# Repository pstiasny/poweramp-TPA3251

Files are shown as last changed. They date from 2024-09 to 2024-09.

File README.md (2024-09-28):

TPA3251-based power amplifier, 2x150W
=====================================

* [View schematic in KiCanvas](https://kicanvas.org/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)
* [View board in KiCanvas](https://kicanvas.org/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)

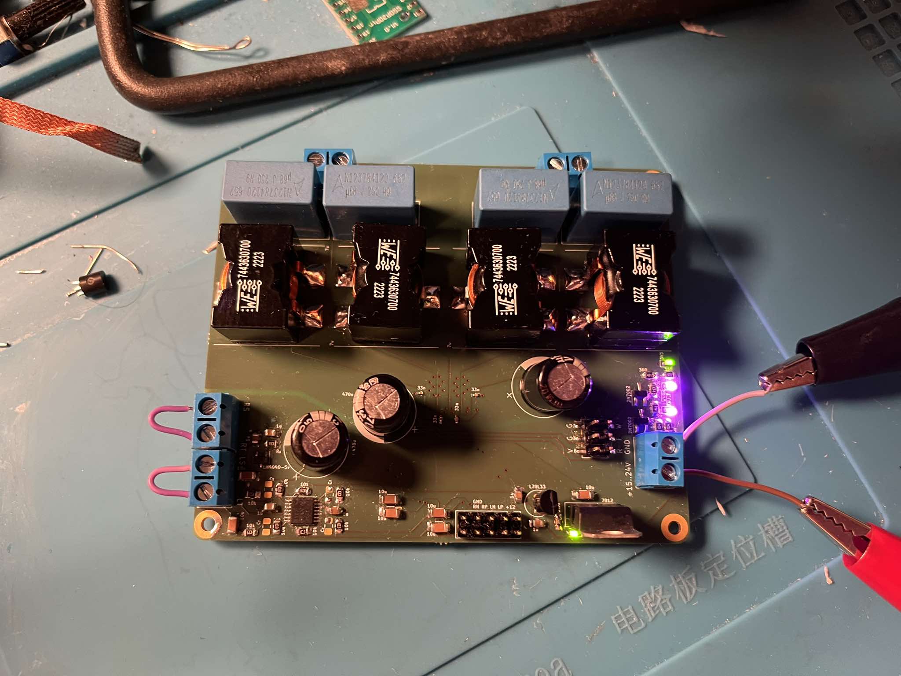
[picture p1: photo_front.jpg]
photo of the top side


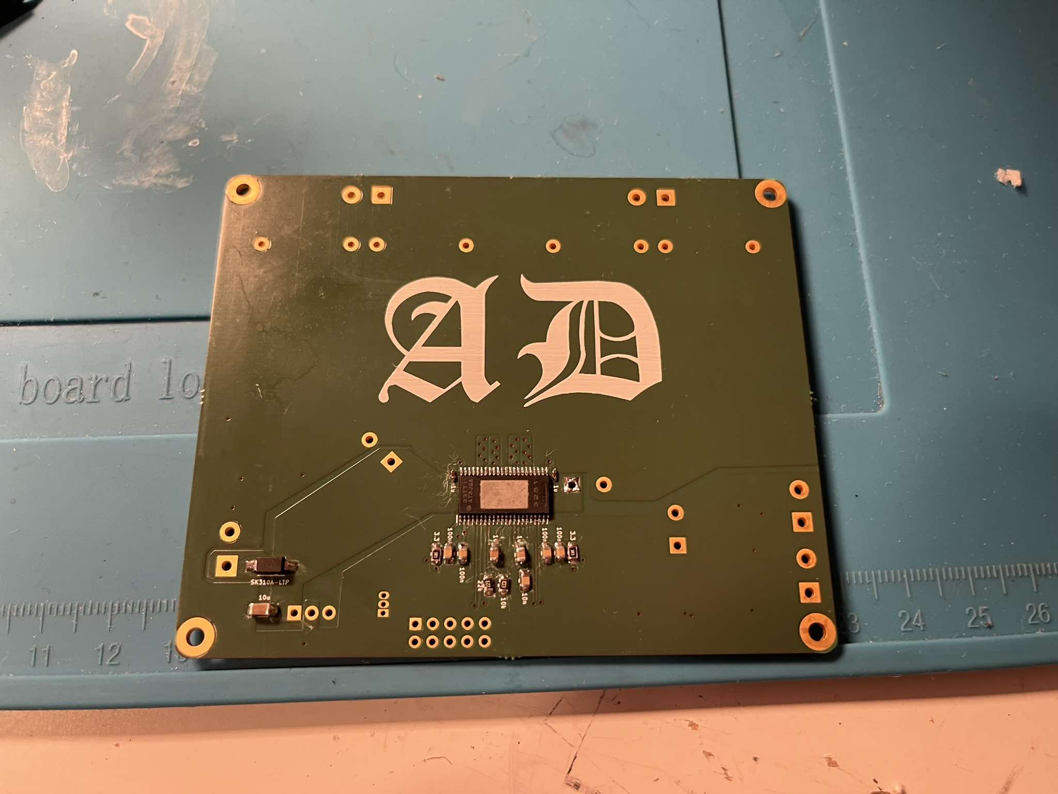
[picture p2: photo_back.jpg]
photo of the back side


## Notes

*  Amplifier chip is placed on the bottom side.  That design allows for thermal coupling to chassis.
*  I had the board bend a little.  Might be better balanced without the bottom layer ground plane.
*  DC relative to power ground will be present on the ouput terminals.  Add AC coupling capacitors
   in series if that is undesired.

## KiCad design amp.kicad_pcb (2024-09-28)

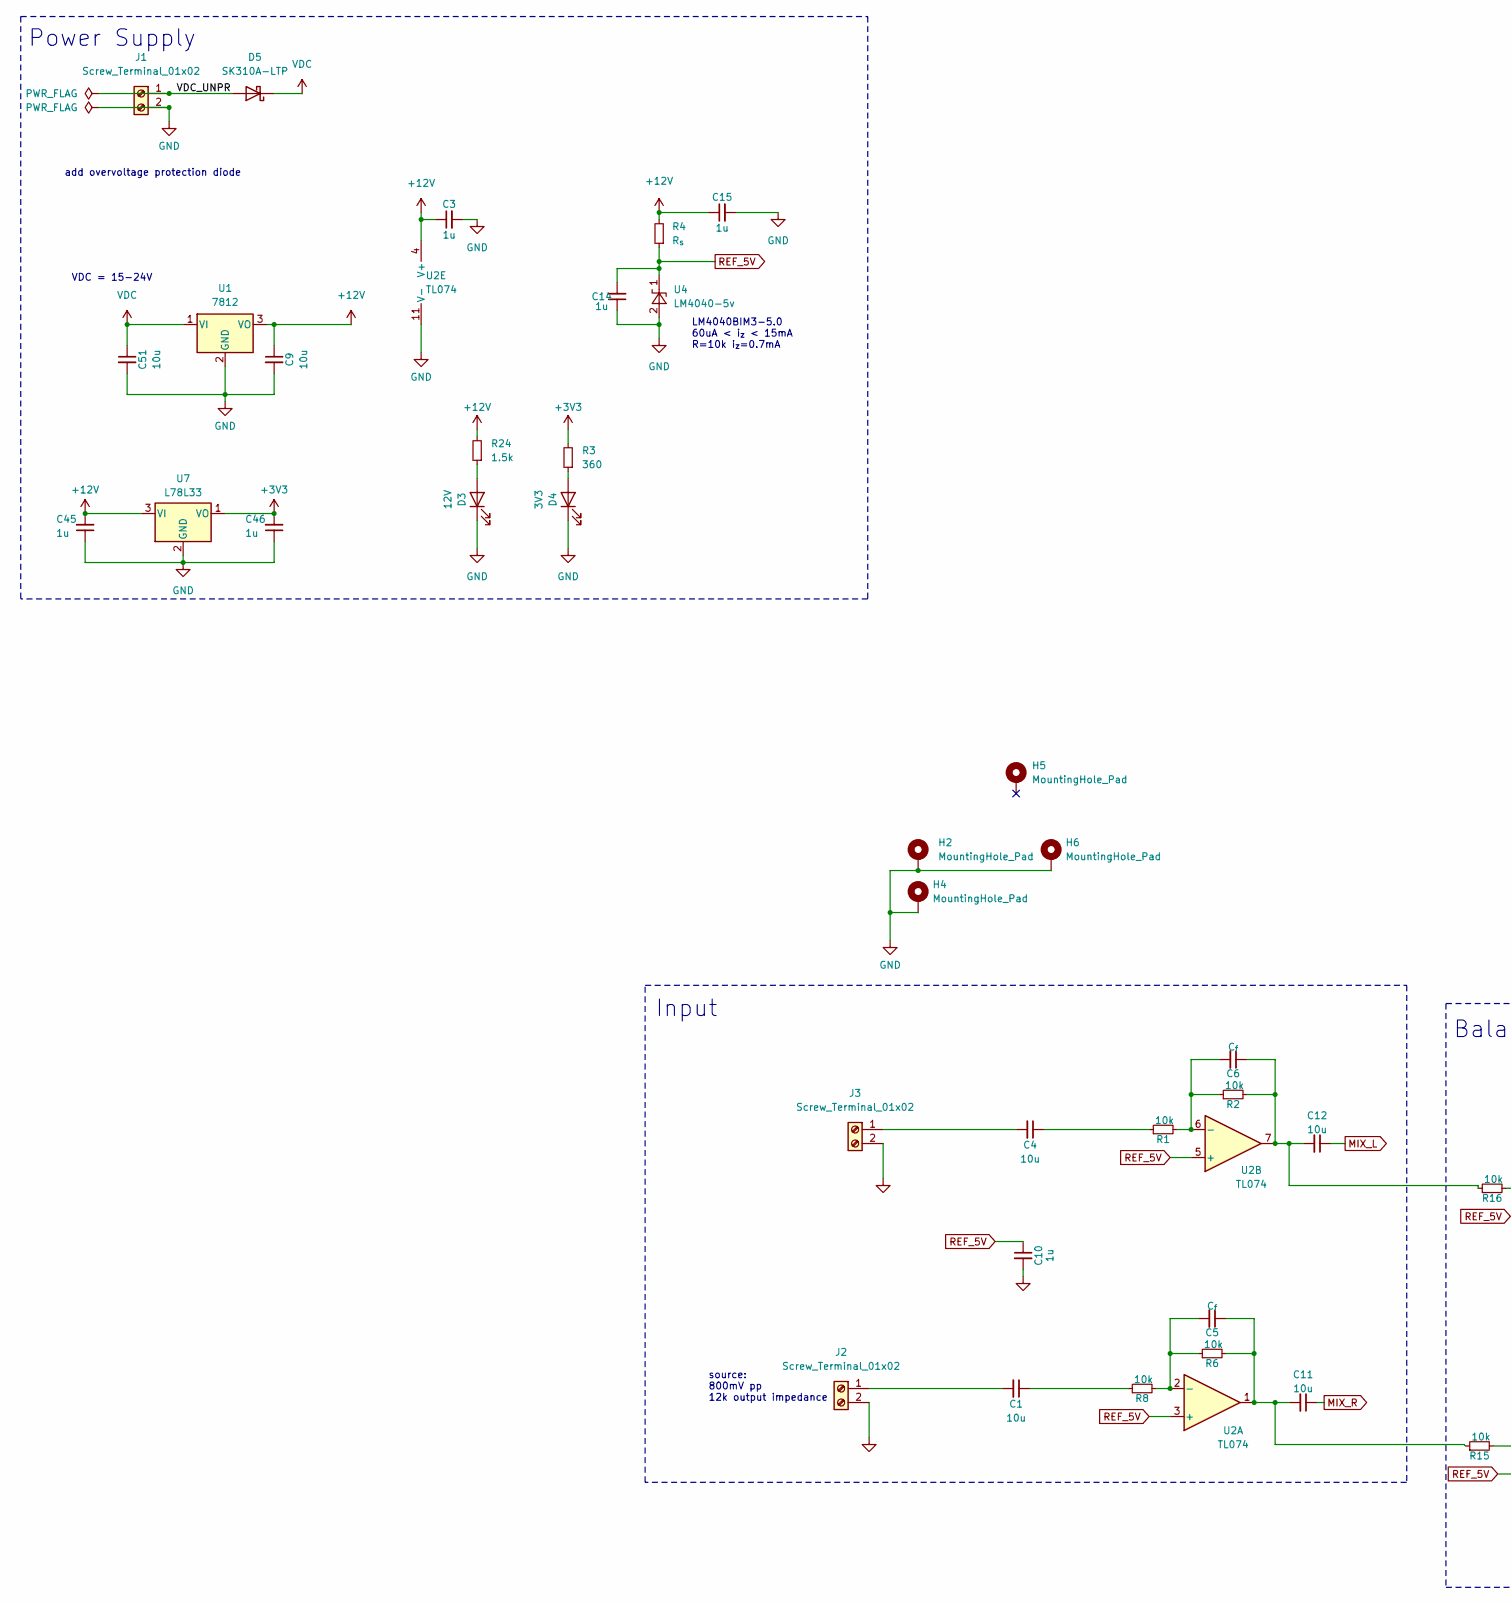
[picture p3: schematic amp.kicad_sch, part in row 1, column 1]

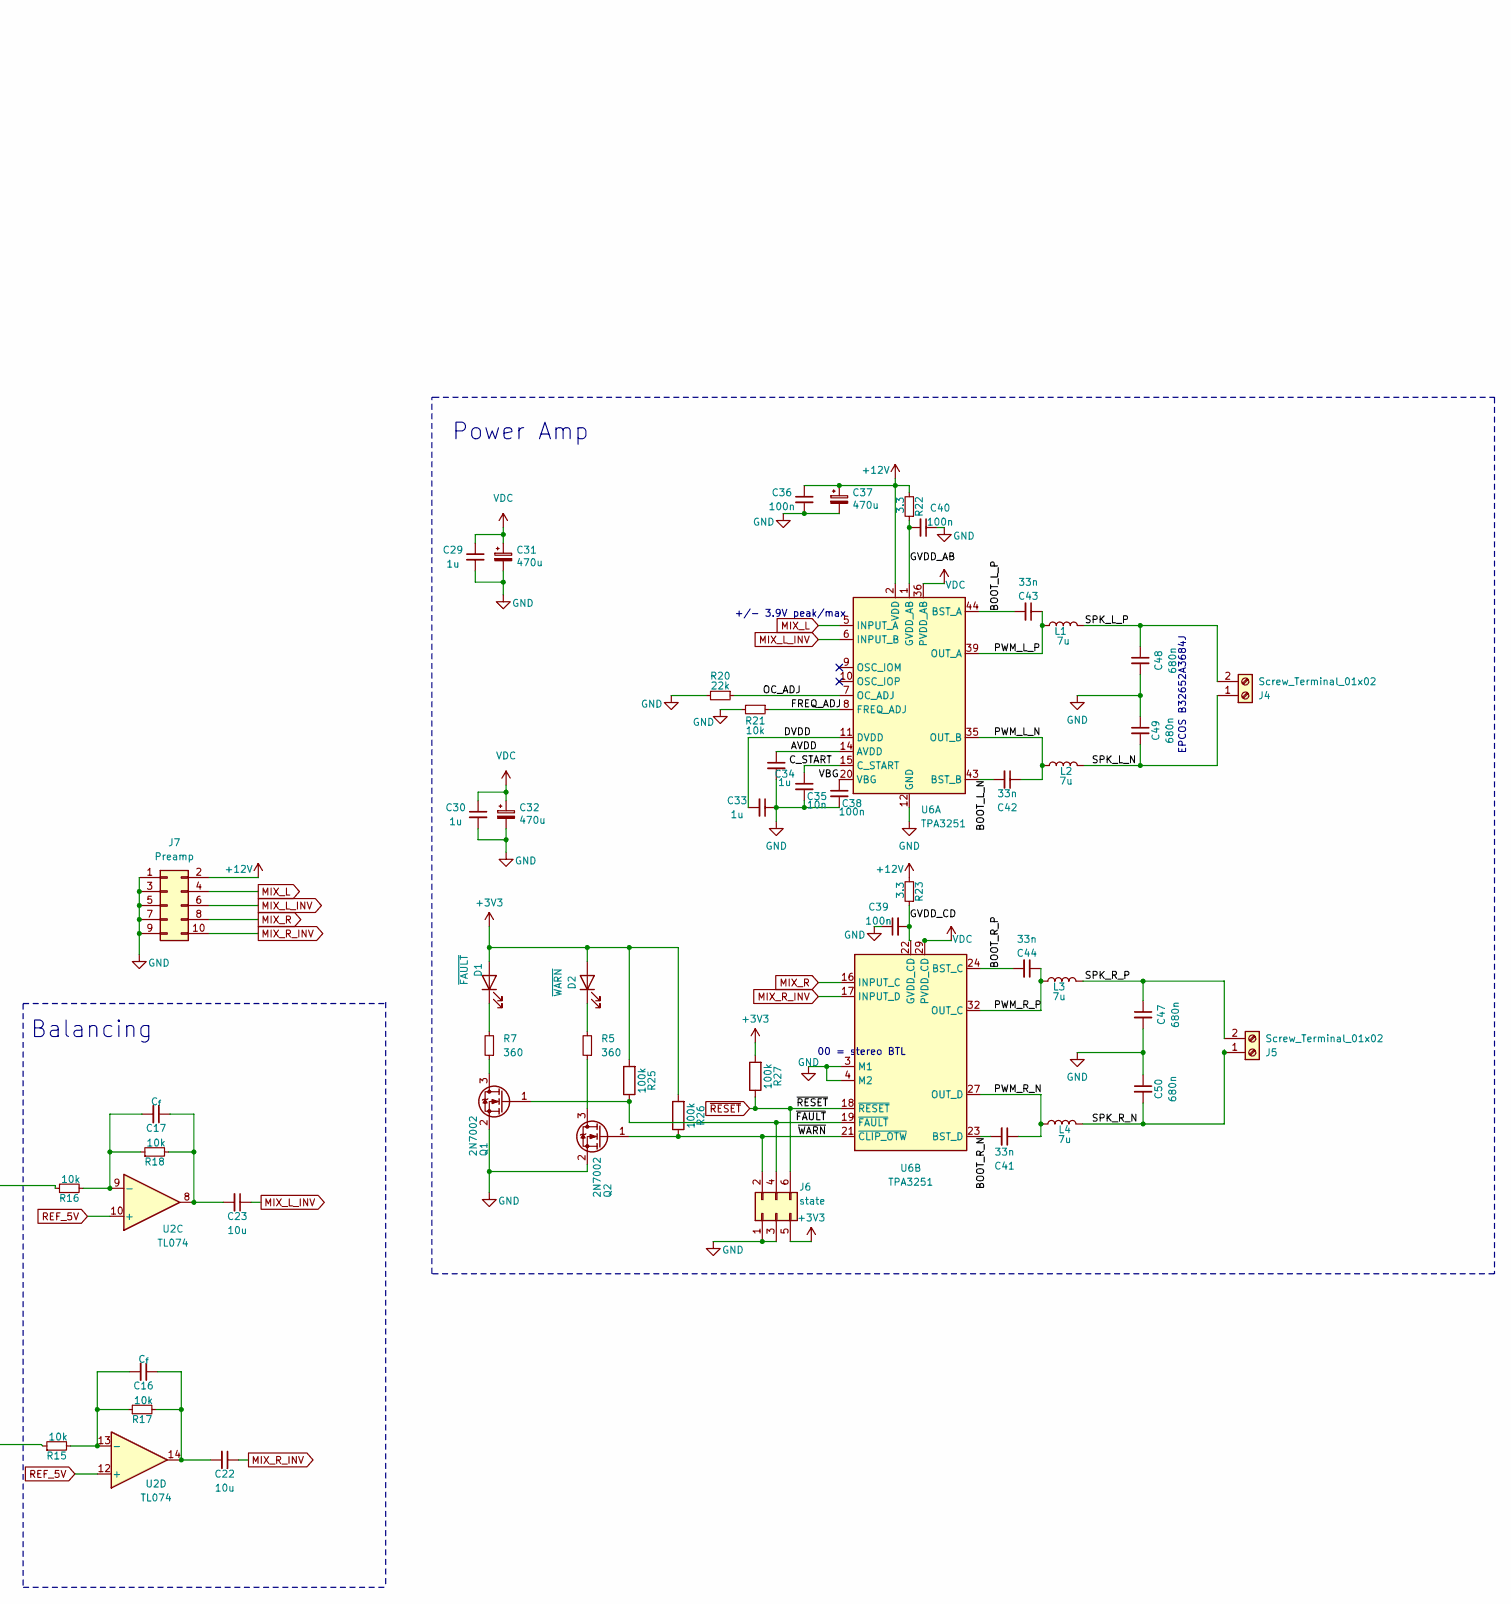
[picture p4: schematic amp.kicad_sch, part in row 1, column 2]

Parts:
C1, C4, C9, C11, C12, C22, C23, C51: 10u; C_1206_3216Metric_Pad1.33x1.80mm_HandSolder
C3, C10, C14, C15, C33, C34, C45, C46: 1u; C_0805_2012Metric_Pad1.18x1.45mm_HandSolder
C5, C6, C16, C17: C_{f}; C_0805_2012Metric_Pad1.18x1.45mm_HandSolder
C29, C30: 1u; C_0402_1005Metric_Pad0.74x0.62mm_HandSolder
C31, C32, C37: 470u; CP_Radial_D12.5mm_P5.00mm
C35: 10n; C_0805_2012Metric_Pad1.18x1.45mm_HandSolder
C36, C38, C39, C40: 100n; C_0805_2012Metric_Pad1.18x1.45mm_HandSolder
C41, C42, C43, C44: 33n; C_0402_1005Metric_Pad0.74x0.62mm_HandSolder
C47, C48, C49, C50: 680n; C_Rect_L18.0mm_W9.0mm_P15.00mm_FKS3_FKP3
D1: ~{FAULT}; LED_0603_1608Metric_Pad1.05x0.95mm_HandSolder
D2: ~{WARN}; LED_0603_1608Metric_Pad1.05x0.95mm_HandSolder
D3: 12V; LED_0603_1608Metric_Pad1.05x0.95mm_HandSolder
D4: 3V3; LED_0603_1608Metric_Pad1.05x0.95mm_HandSolder
D5: SK310A-LTP; SODFL5026X125N
H2, H4, H5, H6: MountingHole_Pad; MountingHole_2.7mm_M2.5_Pad
J1, J2, J3, J4, J5: Screw_Terminal_01x02; TerminalBlock_bornier-2_P5.08mm
J6: state; PinHeader_2x03_P2.54mm_Vertical_SMD
J7: Preamp; PinHeader_2x05_P2.54mm_Vertical
L1, L2, L3, L4: 7u; WE-HCF_201322
Q1, Q2: 2N7002; SOT-23_Handsoldering
R1, R2, R6, R8, R15, R16, R17, R18, R21: 10k; R_0805_2012Metric_Pad1.20x1.40mm_HandSolder
R3, R5, R7: 360; R_0805_2012Metric_Pad1.20x1.40mm_HandSolder
R4: R_{s}; R_0805_2012Metric_Pad1.20x1.40mm_HandSolder
R20: 22k; R_0805_2012Metric_Pad1.20x1.40mm_HandSolder
R22, R23: 3.3; R_0805_2012Metric_Pad1.20x1.40mm_HandSolder
R24: 1.5k; R_0805_2012Metric_Pad1.20x1.40mm_HandSolder
R25, R26, R27: 100k; R_0805_2012Metric_Pad1.20x1.40mm_HandSolder
U1: 7812; TO-220-3_Vertical
U2: TL074; TSSOP-14_4.4x5mm_P0.65mm
U4: LM4040-5v; SOT-23
U6: TPA3251; SOP64P810X120-45N
U7: L78L33; TO-92_Inline

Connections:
+3V3: C46.2, D1.2 (A), D2.2 (A), J6.5, R3.2, R25.2, R26.2, R27.2, U7.1 (VO)
+12V: C3.1, C9.1, C15.1, C36.1, C37.1, C45.2, J7.2, R4.2, R22.2, R23.2, R24.2, U1.3 (VO), U2.4 (V+), U6.2 (VDD), U7.3 (VI)
/AVDD: C34.1, U6.14 (AVDD)
/BOOT_L_N: C42.2, U6.43 (BST_B)
/BOOT_L_P: C43.2, U6.44 (BST_A)
/BOOT_R_N: C41.2, U6.23 (BST_D)
/BOOT_R_P: C44.2, U6.24 (BST_C)
/C_START: C35.1, U6.15 (C_START)
/DVDD: C33.2, U6.11 (DVDD)
/FREQ_ADJ: R21.1, U6.8 (FREQ_ADJ)
/GVDD_AB: C40.2, R22.1, U6.1 (GVDD_AB)
/GVDD_CD: C39.2, R23.1, U6.22 (GVDD_CD)
/OC_ADJ: R20.1, U6.7 (OC_ADJ)
/PWM_L_N: C42.1, L2.1, U6.35 (OUT_B)
/PWM_L_P: C43.1, L1.2, U6.39 (OUT_A), U6.40 (OUT_A)
/PWM_R_N: C41.1, L4.1, U6.27 (OUT_D), U6.28 (OUT_D)
/PWM_R_P: C44.1, L3.2, U6.32 (OUT_C)
/SPK_L_N: C49.2, J4.1, L2.2
/SPK_L_P: C48.1, J4.2, L1.1
/SPK_R_N: C50.2, J5.1, L4.2
/SPK_R_P: C47.1, J5.2, L3.1
/VBG: C38.1, U6.20 (VBG)
/VDC_UNPR: D5.2 (A), J1.1
/~FAULT: J6.4, Q1.1 (G), R25.1, U6.19 (~FAULT)
/~WARN: J6.2, Q2.1 (G), R26.1, U6.21 (~CLIP_OTW)
GND: C3.2, C9.2, C10.2, C14.1, C15.2, C29.2, C30.2, C31.2, C32.2, C33.1, C34.2, C35.2, C36.2, C37.2, C38.2, C39.1, C40.1, C45.1, C46.1, C47.2, C48.2, C49.1, C50.1, C51.2, D3.1 (K), D4.1 (K), H2.1, H4.1, H6.1, J1.2, J2.2, J3.2, J6.1, J6.3, J7.1, J7.3, J7.5, J7.7, J7.9, Q1.2 (S), Q2.2 (S), R20.2, R21.2, U1.2 (GND), U2.11 (V-), U4.2 (A), U6.3 (M1), U6.4 (M2), U6.12 (GND), U6.13 (GND), U6.25 (GND), U6.26 (GND), U6.33 (GND), U6.34 (GND), U6.41 (GND), U6.42 (GND), U7.2 (GND)
MIX_L: C12.1, J7.4, U6.5 (INPUT_A)
MIX_L_INV: C23.1, J7.6, U6.6 (INPUT_B)
MIX_R: C11.1, J7.8, U6.16 (INPUT_C)
MIX_R_INV: C22.1, J7.10, U6.17 (INPUT_D)
unnamed: C1.1, R8.1
unnamed: C4.1, R1.1
unnamed: C5.1, C11.2, R6.2, R15.1, U2.1
unnamed: C6.1, C12.2, R2.2, R16.1, U2.7
unnamed: C16.1, C22.2, R17.2, U2.14
unnamed: C17.1, C23.2, R18.2, U2.8
unnamed: D1.1 (K), R7.2
unnamed: D2.1 (K), R5.2
unnamed: D3.2 (A), R24.1
unnamed: D4.2 (A), R3.1
unnamed: C1.2, J2.1
unnamed: C4.2, J3.1
unnamed: Q1.3 (D), R7.1
unnamed: Q2.3 (D), R5.1
unnamed: C5.2, R6.1, R8.2, U2.2 (-)
unnamed: C6.2, R1.2, R2.1, U2.6 (-)
unnamed: C17.2, R16.2, R18.1, U2.9 (-)
unnamed: C16.2, R15.2, R17.1, U2.13 (-)
REF_5V: C10.1, C14.2, R4.1, U2.3 (+), U2.5 (+), U2.10 (+), U2.12 (+), U4.1 (K)
VDC: C29.1, C30.1, C31.1, C32.1, C51.1, D5.1 (K), U1.1 (VI), U6.29 (PVDD_CD), U6.30 (PVDD_CD), U6.31 (PVDD_CD), U6.36 (PVDD_AB), U6.37 (PVDD_AB), U6.38 (PVDD_AB)
~RESET: J6.6, R27.1, U6.18 (~RESET)

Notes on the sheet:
00 = stereo BTL
Input
EPCOS B32652A3684J
source: 800mV pp 12k output impedance
Power Supply
add overvoltage protection diode
LM4040BIM3-5.0 60uA < i_{z} < 15mA R=10k i_{z}=0.7mA
Balancing
Power Amp
+/- 3.9V peak/max
VDC = 15-24V

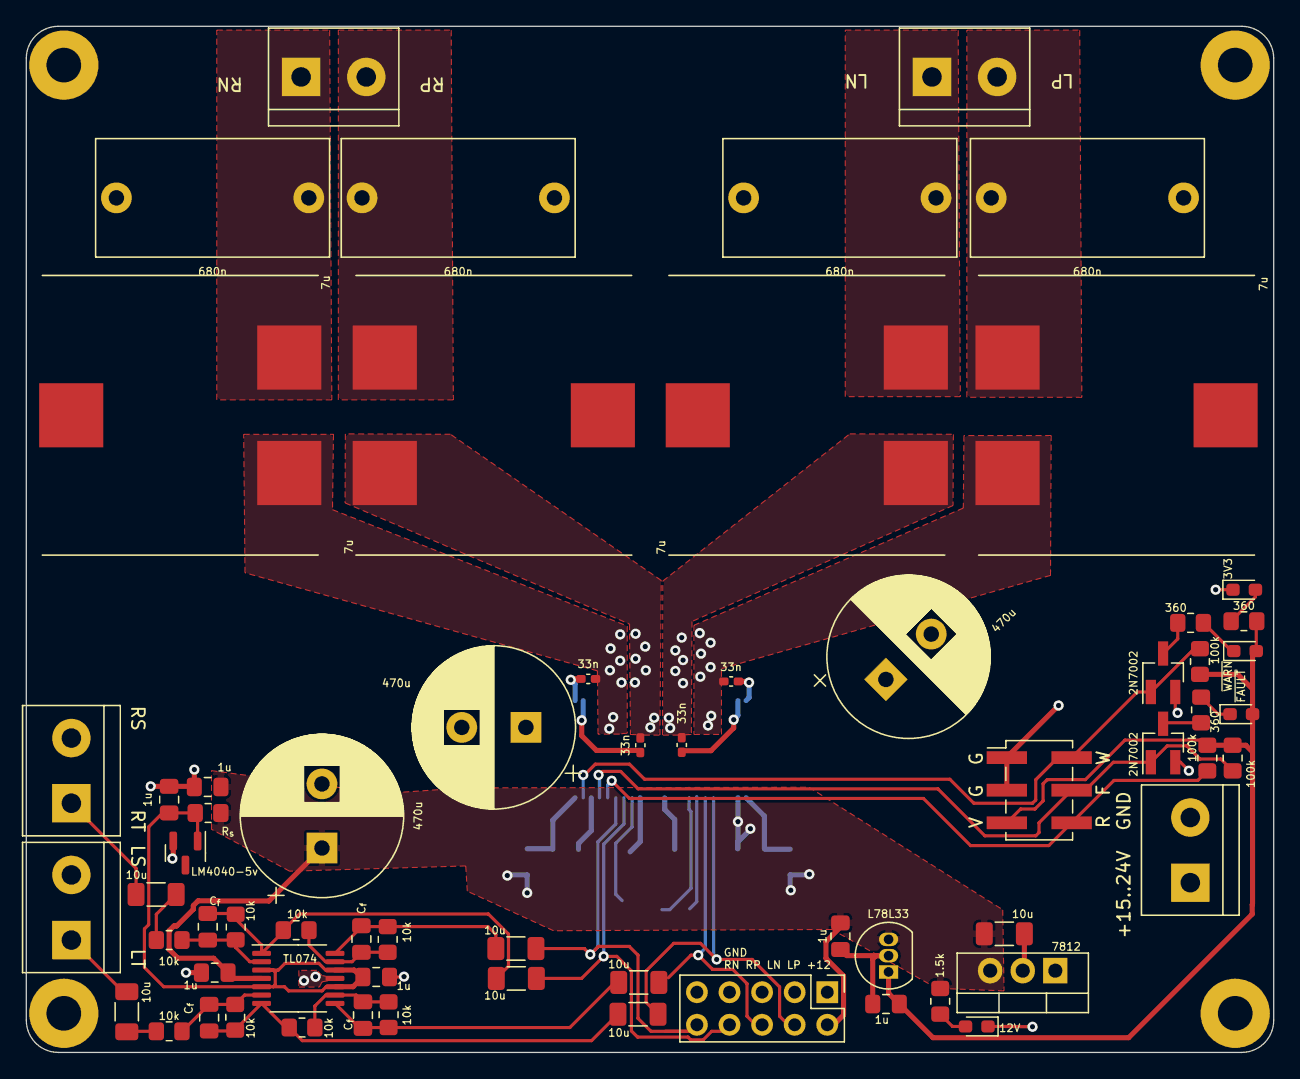
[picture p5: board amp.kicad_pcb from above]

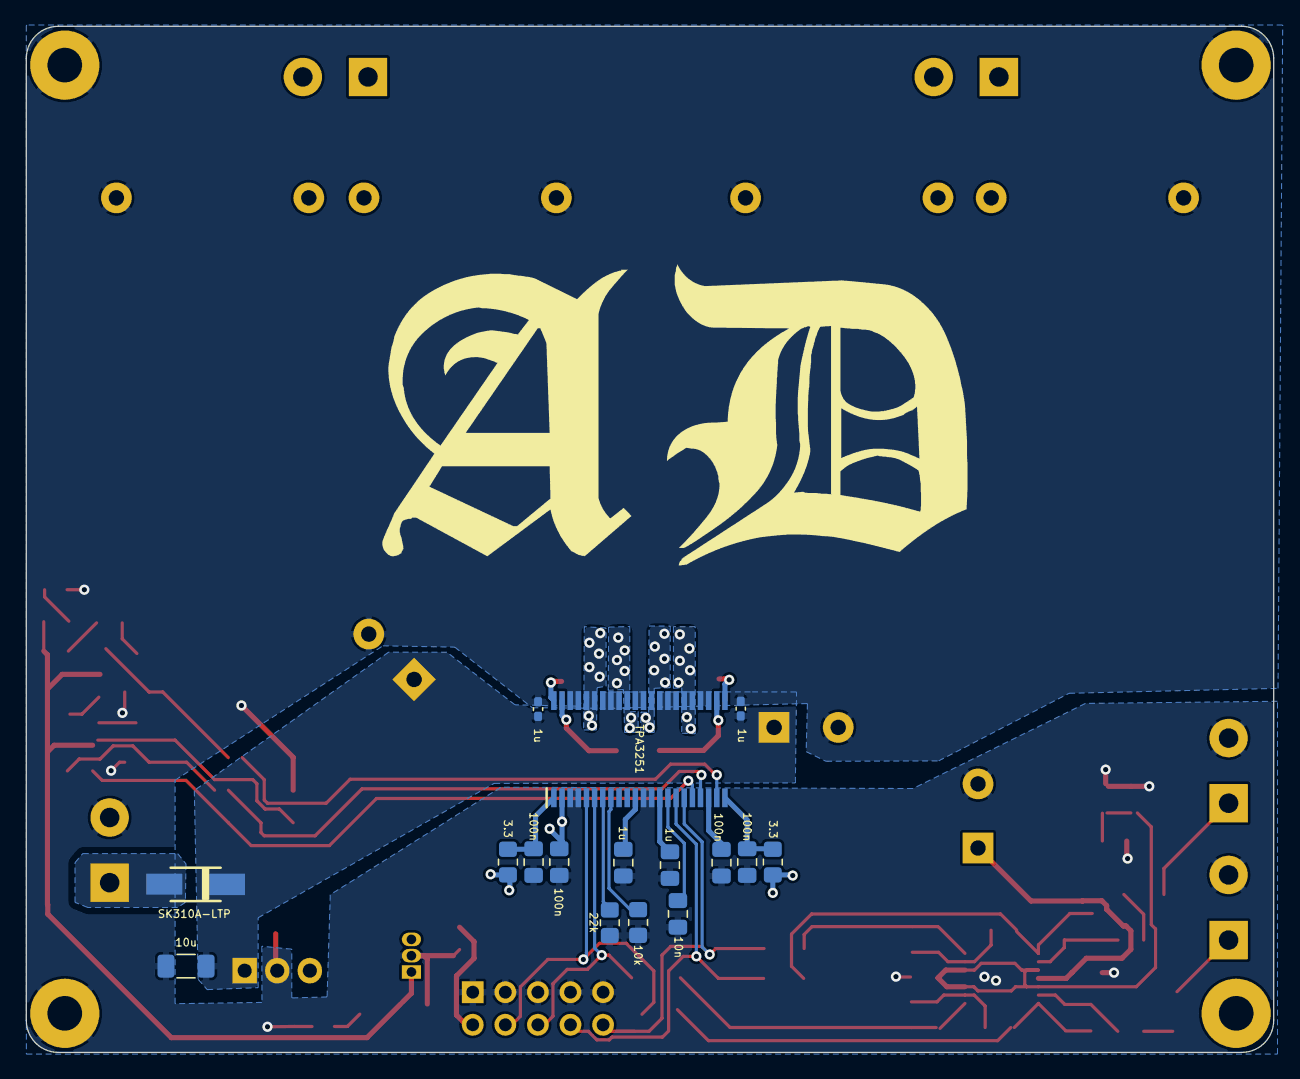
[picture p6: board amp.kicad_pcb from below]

Board: 4 copper layers, 97.2 x 80.0 mm, 85 parts (16 on the bottom side), 51 nets.

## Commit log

2024-09-28 add project files
    [amp.kicad_pcb, amp.kicad_sch]
2024-09-28 schematic annotations
    [amp.kicad_sch]
